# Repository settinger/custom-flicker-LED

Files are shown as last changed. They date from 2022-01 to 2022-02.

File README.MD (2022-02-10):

# A different interpretation of "programmable LED"

TL;DR I'm investigating if I can attach a very very small circuit to a through-hole LED to run a custom programmed pattern, similar to a candle-flicker LED.

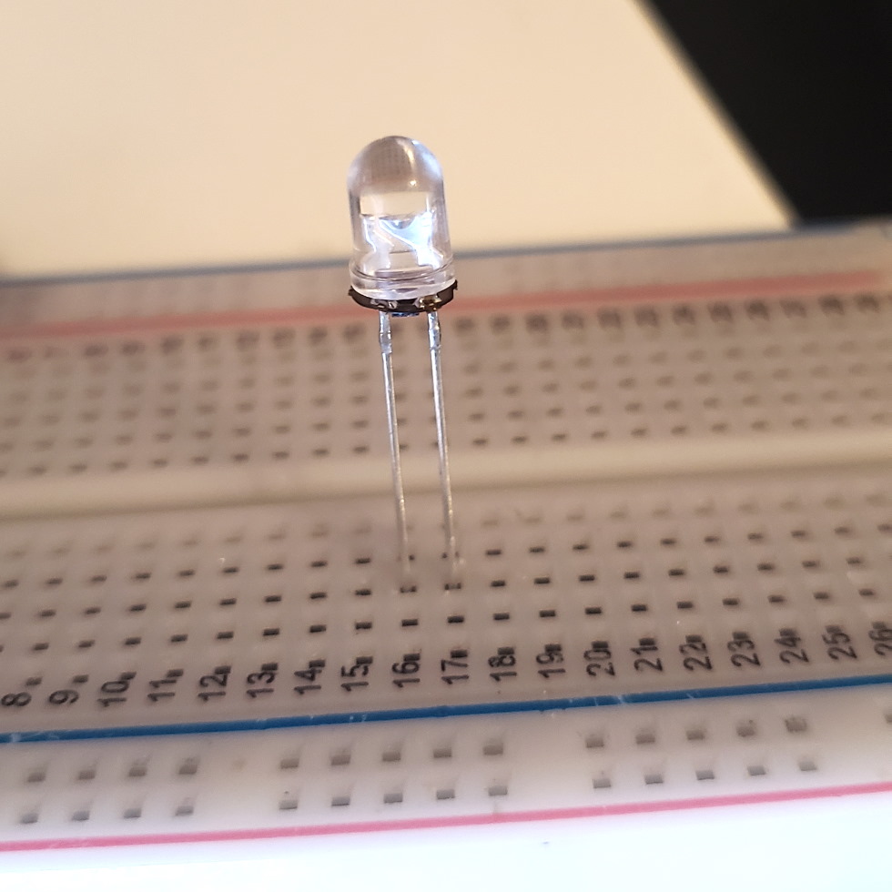
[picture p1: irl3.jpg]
A photograph of a 5mm through-hole LED with a small PCB just barely visible on the underside of the lens


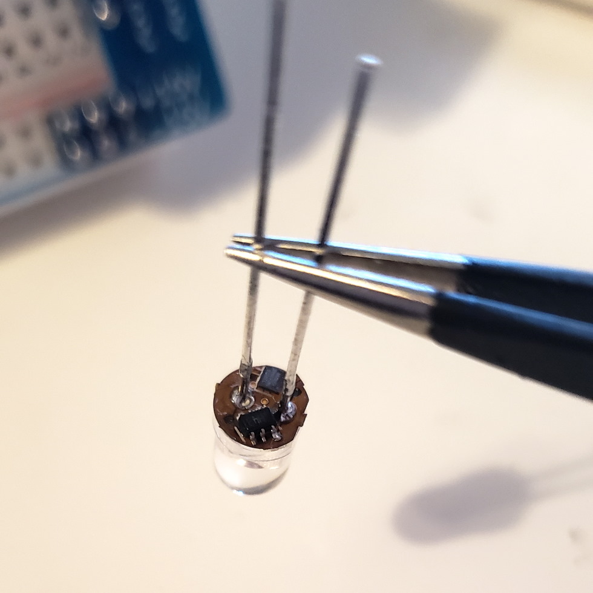
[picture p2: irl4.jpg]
A photograph of a 5mm through-hole LED held in tweezers to expose the small PCB on the underside of the lens


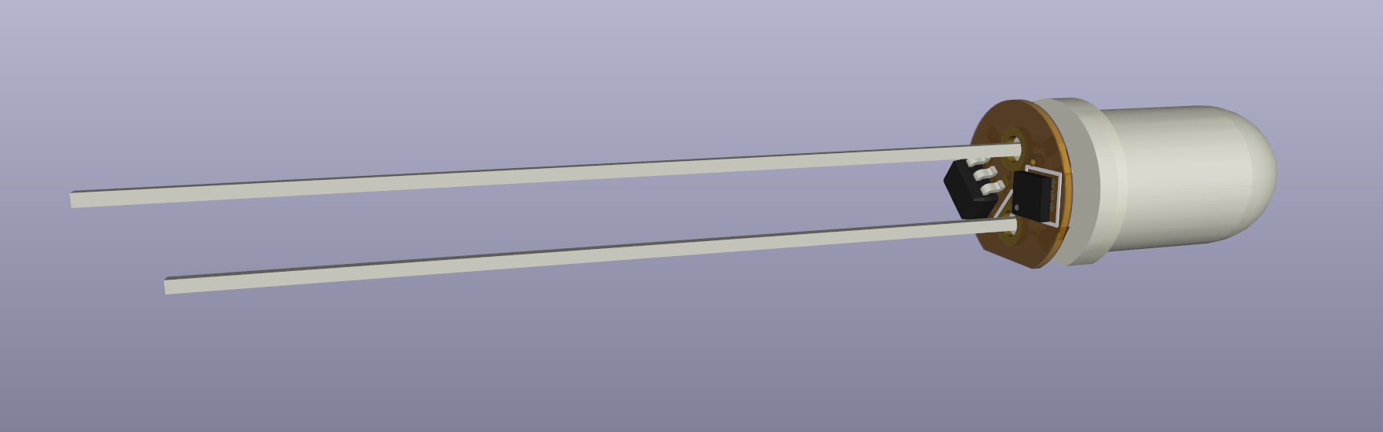
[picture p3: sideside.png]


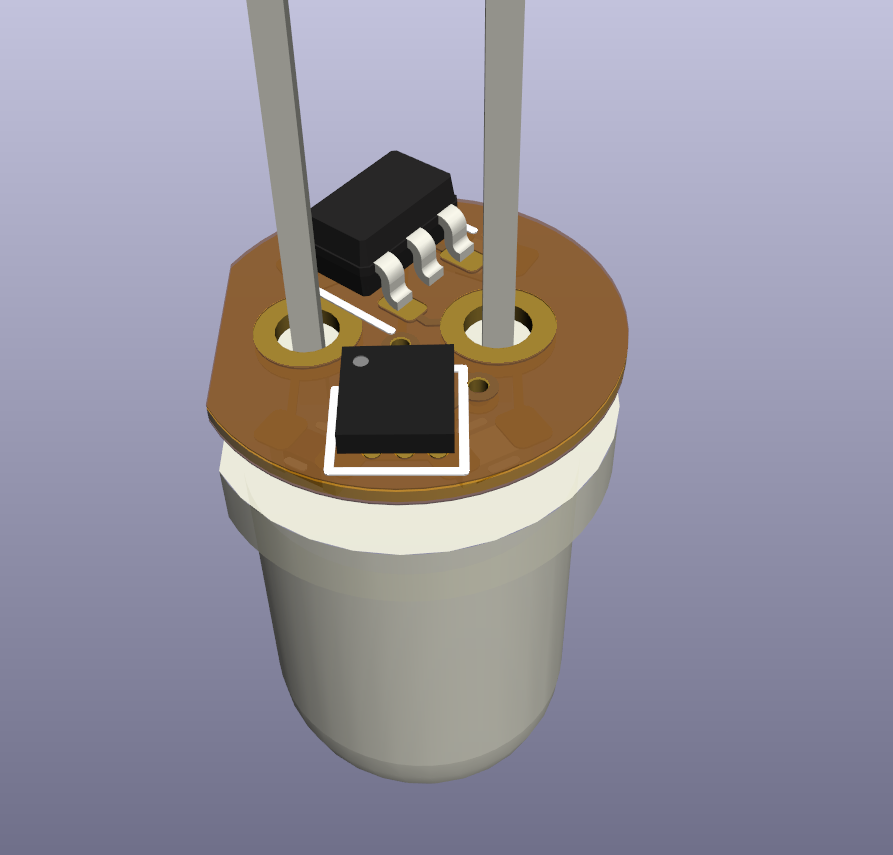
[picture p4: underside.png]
A 3d render of a 5mm through-hole LED with a small PCB on the underside of the lens


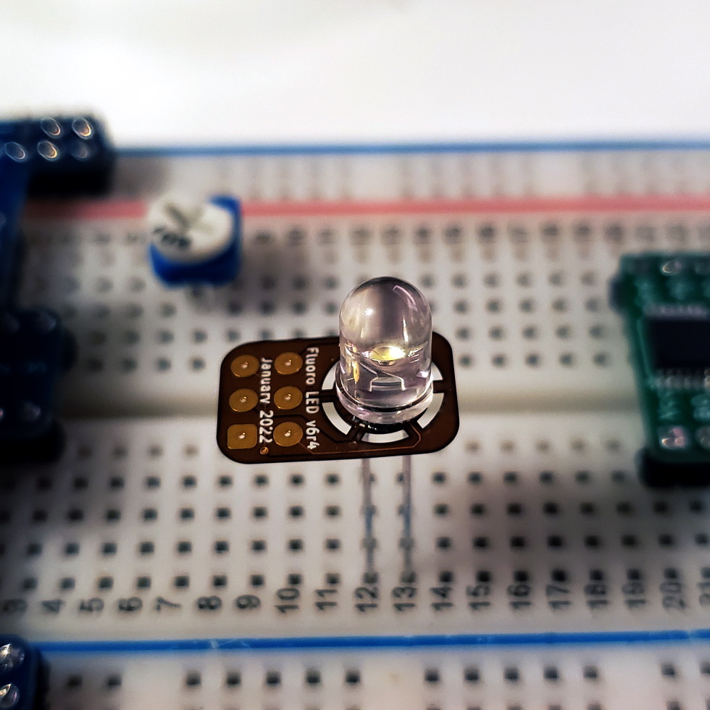
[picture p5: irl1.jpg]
A photograph of a 5mm through-hole LED with a small PCB on the underside of the lens and programming pads sticking out


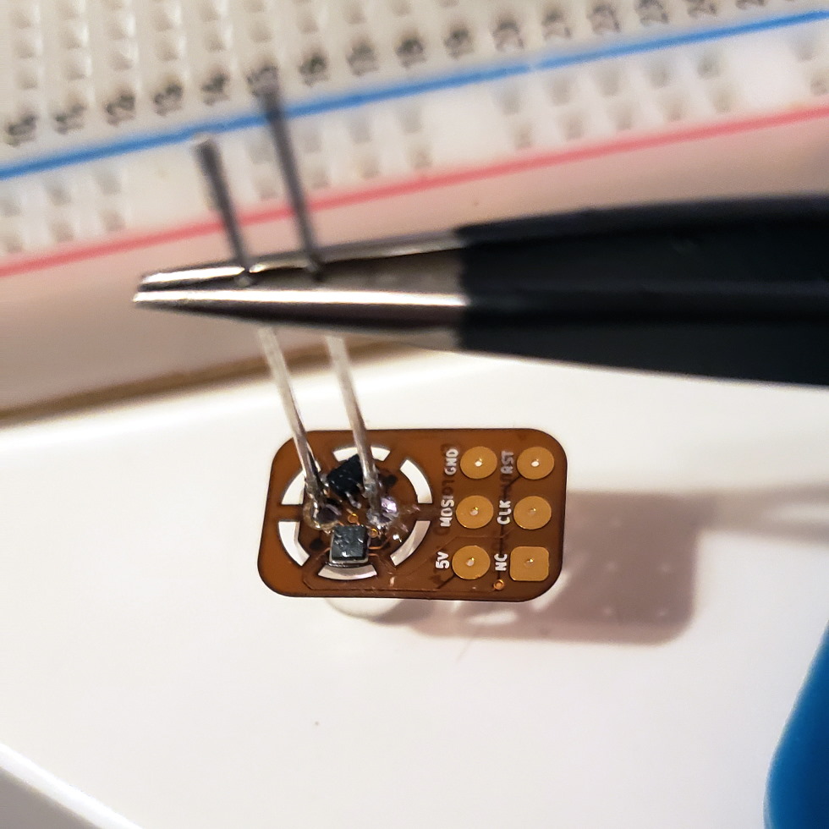
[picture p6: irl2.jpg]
A photograph of a 5mm through-hole LED held in tweezers to expose the small PCB on the underside of the lens, programming pins sticking out


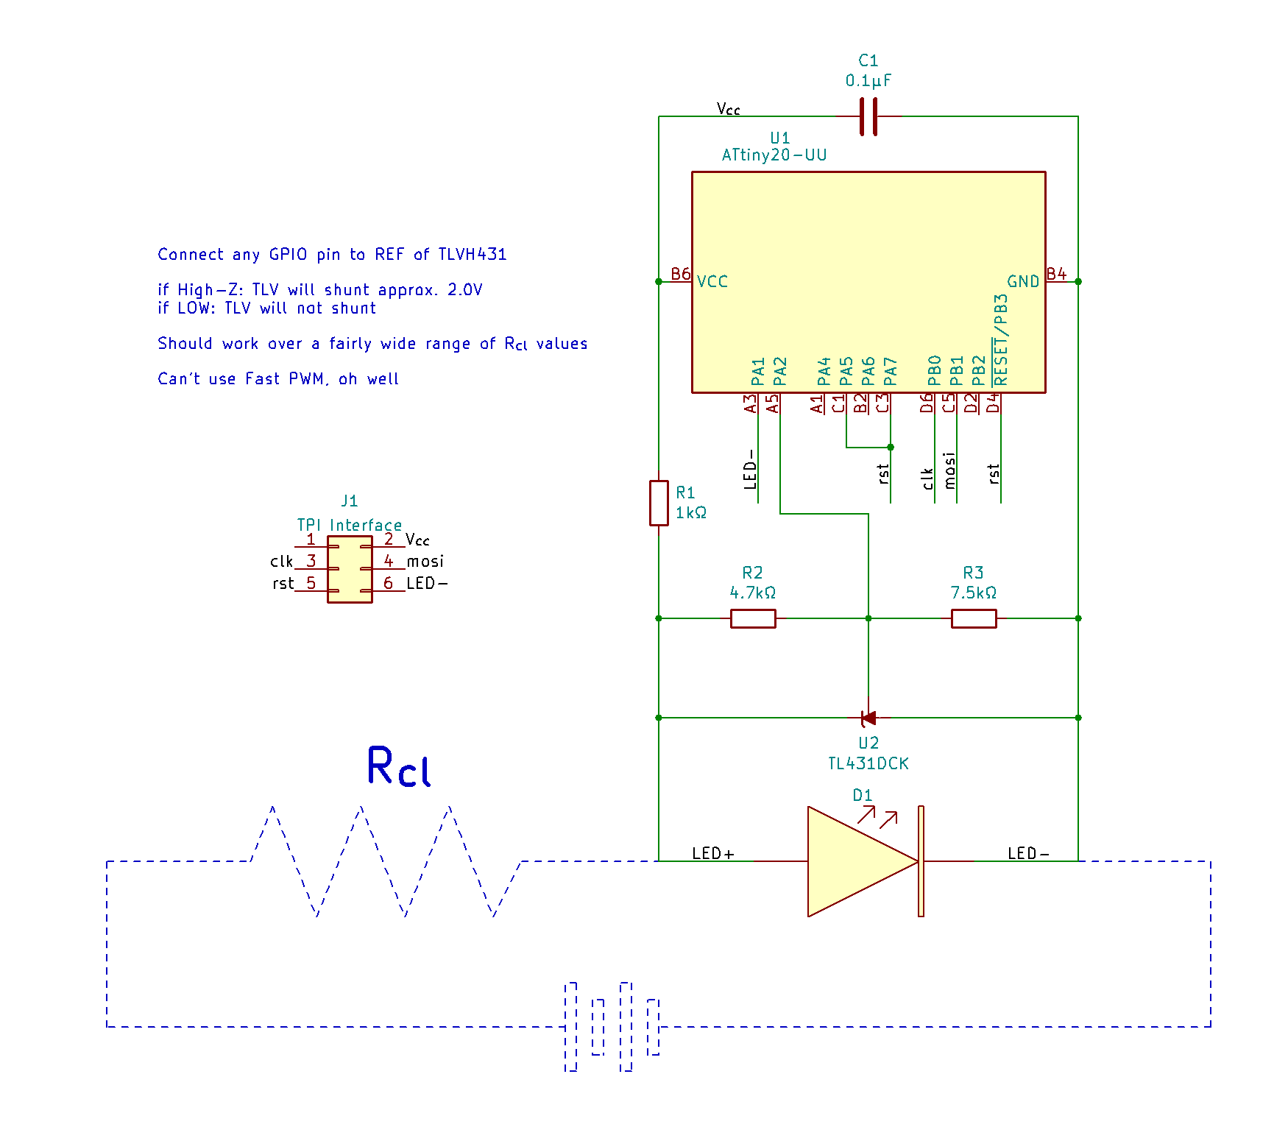
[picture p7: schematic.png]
The schematic of the aforementioned small PCB


## The Concept

A flicker LED is an LED that flickers. More specifically, it is a _drop-in replacement_ for a conventional LED—no need to change the current-limiting resistor, no new calculations for forward voltages, it works just the same as a conventional LED. And they're cheap, too! If you want an LED that flickers like a candle (or one that blinks at a set frequency and duty cycle) you are set for life.

But what if you want a different LED light pattern? In my specific case, I want an LED that turns on like a struggling fluorescent bulb. Or one that stays off most of the time, then suddenly lights up the room like lightning. Or a pseudo-status LED that blinks at random frequencies to trick the viewer into thinking some complex process is running. Or...anything, really. A programmable LED!

Do programmable LEDs like this exist? Obviously the WS2812b and similar LEDs exist, and those are frequently called "programmable LEDs". But those are pretty different than, say, a flicker LED. You still need a controller of some variety to tell the WS2812b what pattern to perform, which is not the case for a flicker LED, and not the case for the LEDs I'm envisioning.

## The Circuit

So can it be done? Without designing a custom IC and embedding it in a custom LED casing? I need a solution compatible with a stock LED. And that means the solution needs to exist _in parallel with the LED_. I'm envisioning a small PCB nestled underneath a 5mm through-hole LED. Soldered in place between the existing legs, no cuts or modifications to the LED itself.

What microcontroller is small enough to fit under a 5mm through-hole LED? I know of two: the WLCSP-12 ATtiny20 (1.55×1.43 mm) and the WLP-16 MAX32660 (1.55×1.57 mm). It's true that I've been meaning to get better with ARM systems, but for now I'll stick with the more familiar AVR-based ATtiny20.

Both those microcontrollers require at least 1.8V to operate. A white LED drawing between 1 and 20 mA will have a forward voltage in roughly the 2.4 - 3.1 V range. That means a microcontroller in parallel can be powered while the LED is on! However, if the LED shuts off, the voltage across it drops to 0V and the microcontroller will shut off as well. To get around this, we can make the LED super dim instead of completely turned off. If we use a shunt to get the LED forward voltage into the 1.8 - 2.0 V range, the microcontroller can stay on while the LED light output is undetectable. A TLVH431 adjustable shunt lets us keep the same forward voltage, regardless of if the shunt is carrying 1 mA or 20 mA, which makes things more consistent than a Zener diode can do.

My original plan was to shunt current around the LED using a BJT driven by an I/O pin on the microcontroller. This would be paired with a Zener diode to keep the LED voltage at at least 1.8V, to ensure the microcontroller has enough power. There were some issues with this approach! For one thing, I learned that low-value Zeners have much more variation in their breakdown voltages. A diode sold as a 1.8V Zener might, at a current of 10 mA, have a breakdown voltage closer to 2.6V; this wouldn't dim the LED at all!

Another issue was the transistor. I didn't realize that I could sink ~20 mA directly into these microcontrollers' GPIO pins! In fact, the ATtiny20 GPIO can source/sink 40 mA, and the MAX32660 can do 25. This means the current being diverted around the LED can go through the microcontroller, instead of an external transistor. Thank you to [cpldcpu](https://cpldcpu.wordpress.com) for pointing this out to me! I don't know what led me to think that a BGA ATtiny could handle less current than SOIC or DIP equivalents. That set off a cascade of design adjustments that led to the current very-low-component-count design.

## Putting it together

A photograph of a 5mm through-hole LED with a small PCB on the underside of the lens and programming pads sticking out

It's working! [Here is a video of the flicker in action](https://twitter.com/DHammarskjold/status/1491195660074627072). The flicker animation is a port of one kindly provided by [Emily Velasco](https://twitter.com/MLE_Online), which you can obtain in the `code/` folder.

[As you can see here](https://twitter.com/DHammarskjold/status/1490858013917208579), there was a (relatively) large PCB still attached to the LED. Those are the programming pads, so I can tweak the program on the ATtiny20 until I decide to trim off the excess parts.

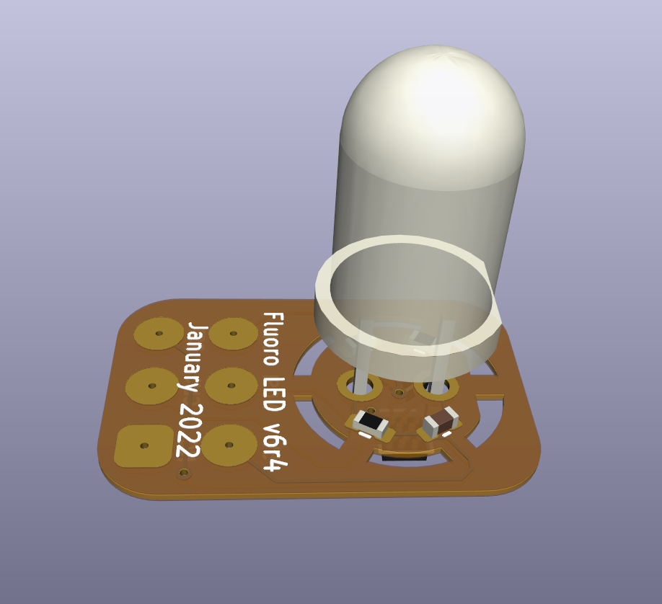
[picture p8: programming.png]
A 3d render of the small PCB inside a larger PCB with pads for connecting a programmer


There are components on both sides of the PCB. I put the ATtiny20 and TLVH431 on first, using a hot plate. Then I programmed the tiny20, and finally I hand-soldered the 0402 passives. I used a 47kΩ and a 68kΩ resistor instead of the desired 4.7kΩ and 7.5kΩ ones because that's what I had on hand.

[Here is a tweet showing my protoboard circuit](https://twitter.com/DHammarskjold/status/1483334537580998658), working as expected with larger versions of each part. This helped me dial in the right resistor values and measure the range of current that kept the board functioning. According to my cheap ammeter, the microcontroller functions properly on a supply as low as 0.5 mA and as high as 20 mA, which I'm thrilled to see.

Please let me know if you have some suggestions for improvements to the fluorescent-flicker animation, or if there are other programmable LED animations you'd like to see! I have a few ideas for a 5mm RGB LED, but that's a project for another time....

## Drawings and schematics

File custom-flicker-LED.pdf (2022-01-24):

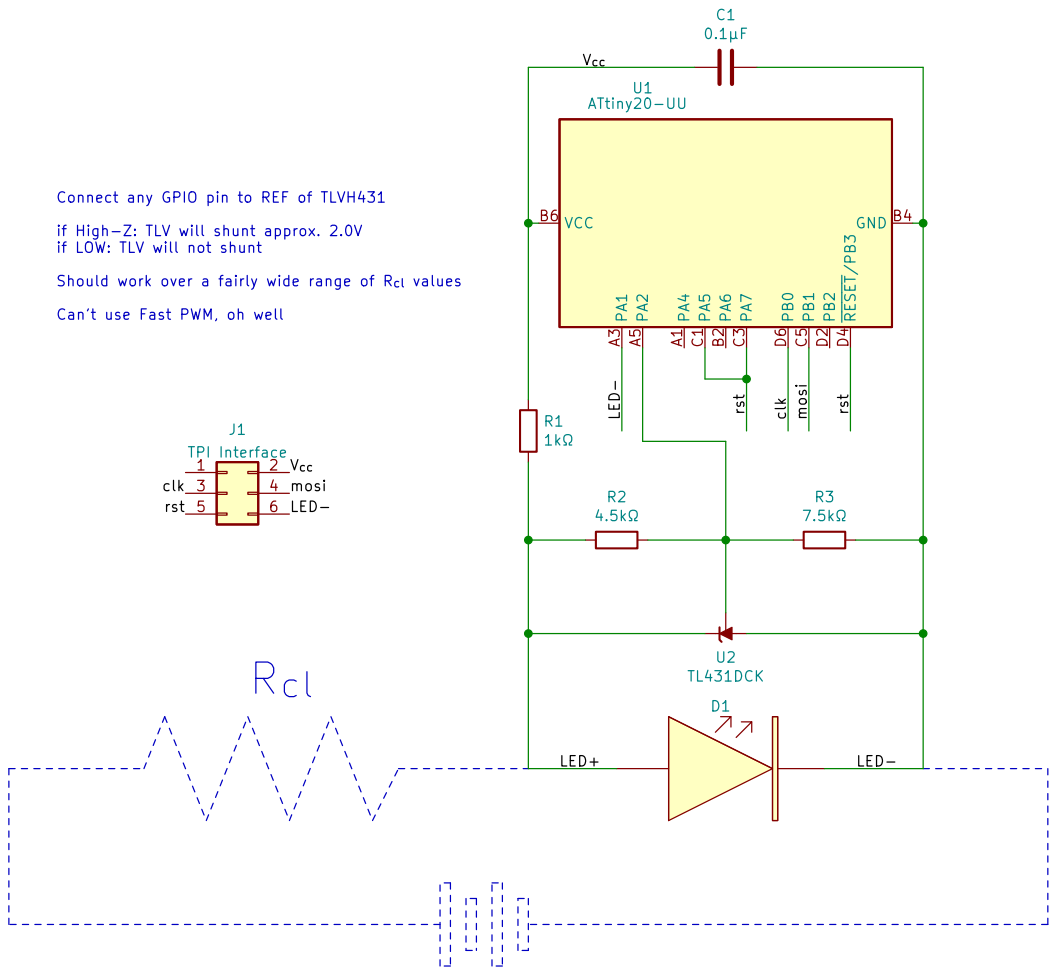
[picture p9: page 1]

Connect any GPIO pin to REF of TLVH431

if High-Z: TLV will shunt approx. 2.0V
if LOW: TLV will not shunt Should work over a fairly wide range of R_{cl} values Can't use Fast PWM, oh well

File: custom-flicker-LED.kicad_sch Sheet: /
Id: 1/1 Title:

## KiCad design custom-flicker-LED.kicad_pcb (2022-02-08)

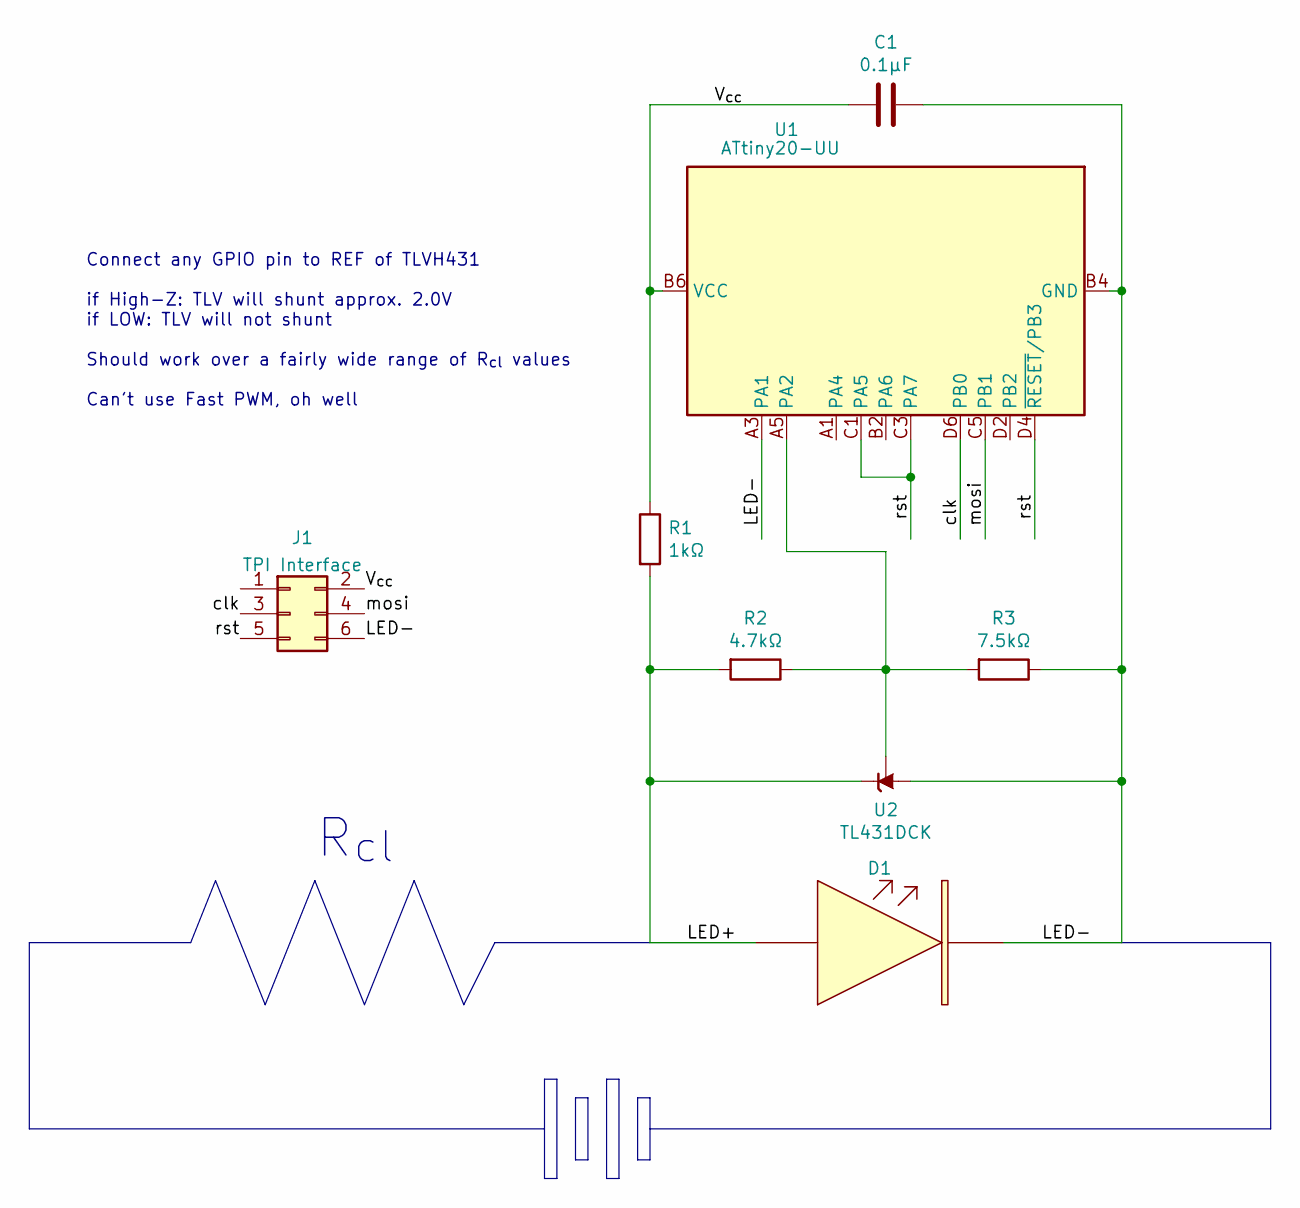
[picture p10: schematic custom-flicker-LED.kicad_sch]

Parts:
C1: 0.1μF; C_0402_1005Metric
D1: LED_big; LED_D5.0mm_Clear
J1: TPI Interface; PinHeader_2x03_P2.54mm_Vertical
R1: 1kΩ; R_0402_1005Metric
R2: 4.7kΩ; R_0402_1005Metric
R3: 7.5kΩ; R_0402_1005Metric
U1: ATtiny20-UU; WLCSP-12_1.403x1.555mm_P0.4mm_Stagger
U2: TL431DCK; SOT-363_SC-70-6

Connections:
/LED+: D1.2 (A), R1.2, R2.2, U2.1 (K)
/LED-: C1.1, D1.1 (K), J1.6, R3.1, U1.A3 (PA1), U1.B4 (GND), U2.6 (A)
/V_{cc}: C1.2, J1.2, R1.1, U1.B6 (VCC)
/clk: J1.3, U1.D6 (PB0)
/mosi: J1.4, U1.C5 (PB1)
/rst: J1.5, U1.C1 (PA5), U1.C3 (PA7), U1.D4 (~RESET/PB3)
unnamed: R2.1, R3.2, U1.A5 (PA2), U2.3 (REF)

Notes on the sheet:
R_{cl}
Connect any GPIO pin to REF of TLVH431 if High-Z: TLV will shunt approx. 2.0V if LOW: TLV will not shunt Should work over a fairly wide range of R_{cl} values Can't use Fast PWM, oh well

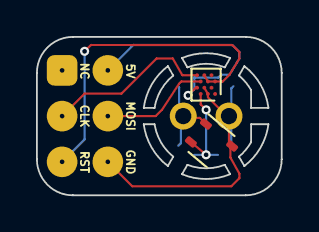
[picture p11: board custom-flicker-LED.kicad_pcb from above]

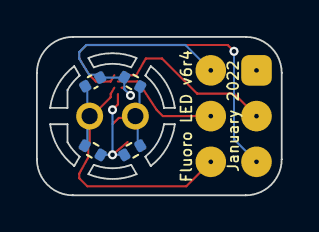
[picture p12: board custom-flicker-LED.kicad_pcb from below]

Board: 2 copper layers, 13.6 x 8.8 mm, 8 parts (5 on the bottom side), 7 nets.

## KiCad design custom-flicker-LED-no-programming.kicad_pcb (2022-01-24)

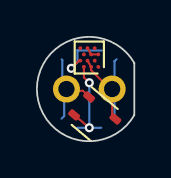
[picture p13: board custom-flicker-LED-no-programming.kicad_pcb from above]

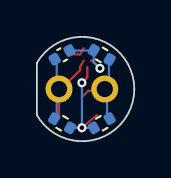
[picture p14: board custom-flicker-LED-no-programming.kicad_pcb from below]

Board: 2 copper layers, 5.4 x 5.8 mm, 7 parts (5 on the bottom side), 5 nets.

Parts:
C1: 0.1μF; C_0402_1005Metric
D1: LED_big; LED_D5.0mm_Clear
R1: 1kΩ; R_0402_1005Metric
R2: 4.5kΩ; R_0402_1005Metric
R3: 7.5kΩ; R_0402_1005Metric
U1: ATtiny20-UU; WLCSP-12_1.403x1.555mm_P0.4mm_Stagger
U2: TL431DCK; SOT-363_SC-70-6

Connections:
/LED+: D1.2 (A), R1.2, R2.2, U2.1 (K)
/LED-: C1.1, D1.1 (K), R3.1, U1.A3 (PA1), U1.B4 (GND), U2.6 (A)
/V_{cc}: C1.2, R1.1, U1.B6 (VCC)
/rst: U1.C1 (PA5), U1.C3 (PA7), U1.D4 (~RESET/PB3)
unnamed: R2.1, R3.2, U1.A5 (PA2), U2.3 (REF)

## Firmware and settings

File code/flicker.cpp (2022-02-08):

/*
 * flicker_t20.cpp
 * A port of this algorithm: https://github.com/emilyvelasco/flickery_light/blob/main/flickery_light_w_warmup.ino
 * Important datasheet: http://ww1.microchip.com/downloads/en/DeviceDoc/atmel-8235-8-bit-avr-microcontroller-attiny20_datasheet.pdf
 *
 * When PA2 is High-Z, current is shunted through TLVH431
 * and LED anode is driven to approximately 2V.
 *
 * When PA2 is LOW, TLV431 is driven as high as possible
 * and current flows through the LED as normal.
 *
 * When PA2 is HIGH, the LED anode is driven to 1.24V
 * which will cause the system to reset. Not advised.
 *
 * Created: 1/16/2022 3:35:08 PM
 * Author : Sam Ettinger <ettingersam@gmail.com> https://github.com/settinger/custom-flicker-LED
 */
#define F_CPU 4000000UL
#include <avr/io.h>
#include <avr/interrupt.h>

// Declare constants and variables
#define INTERRUPT_DELAY 100U                            // Number of processor cycles in the smallest binary code modulation frame
#define NUM_FRAMES 6                                    // Number of binary code modulation frames per period
#define UPDATE_DELAY 20                                 // Number of periods to elapse before re-calculating the LED brightness
volatile unsigned int interruptDelay = INTERRUPT_DELAY; // How many cycles long is the current frame; loops between 100, 200, 400, 800, 1600, 3200
volatile int frame = 0;                                 // Which binary-code-modulation frame we are currently on; loops between 0, 1, 2, 3, 4, 5
volatile unsigned int brightness = 0;                   // A value between 0 and 63 determining the duty cycle of the LED (0: off, 63: fully on)
volatile unsigned char updateDelay = 0;                 // How many periods of binary code modulation have elapsed since LED brightness was last calculated

volatile unsigned int randomLevel;                      // A random number to determine if LED is on or not
volatile unsigned int lightLevel;                       // A random number that is the LED brightness
volatile unsigned int cutoffValue = 127;                // By comparing this to a random 7-bit number we determine how likely the LED is to be on or off at a given moment.
volatile unsigned int bottomRandom = 2;                 // The lowest acceptable brightness for the LED at this current moment
volatile bool slowdown = false;                              // Slows down the speed at which bottomRandom increases

// Write to the 16-bit register pair OCR1A
void setTimer1(unsigned int i) {
	unsigned char sreg;
	sreg = SREG; // Save global interrupt flag
	cli(); // Disable interrupts
	OCR1A = i; // Write value to register pair
	TCNT1 = 0; // Reset counter
	SREG = sreg; // Restore global interrupt flag
}

// Set the LED to one of 64 brightness levels
void setBrightness (unsigned int i) {
	brightness = i & 0x3F;
}

// Gather entropy from ADC
int getEntropy(int bits) {
	int entropy = 0;
	for (int bit = 0u; bit < bits; bit++) {
		// Start ADC collection
		ADCSRA |= 1 << ADSC;
		// Wait for ADC conversion to finish (25 clock cycles the first time, 13 cycles afterward)
		while (ADCSRA & 1 << ADSC) {
			;
		}
		// Fetch LSB of ADC result and put it in the entropy variable
		entropy |= (ADC & 1) << bit;
		
		// Delay a little bit before taking next measurement
		if (bit < (bits - 1)) {
			int n = 0;
			while (n < 30) {
				n++;
			}
		}
	}
	return entropy;
}

// Calculate the new brightness
void flicker() {
	// Pick random number to determine if light is on or off
	randomLevel = getEntropy(7);
	
	// Lower cutoff level over time to reduce flicker gradually
	if (cutoffValue > 0) {
		cutoffValue--;
	}
	
	// If LED should be on, set it to the calculated brightness
	if (randomLevel >= cutoffValue) {
		lightLevel = getEntropy(5);
		lightLevel = bottomRandom + (lightLevel % (63 - bottomRandom));
		setBrightness(lightLevel);
	} else {
		setBrightness(0);
	}
	
	// Increase minimum brightness value until full brightness is achieved, but maintain some flicker
	slowdown = !slowdown;
	if (slowdown) {
		bottomRandom++;
		if (bottomRandom > 50) {
			bottomRandom = 50;
		}
	}
}

int main(void) {
	// Set clock prescaler to 4 (i.e. 2 MHz system clock) (Datasheet p.21)
	CCP = 0xD8;
	CLKPSR = 0b0001;
	
	// Set PA2 to high-Z condition initially (Datasheet p.44)
//	PORTCR = 1 << BBMA; // Break-before-make enabled; I don't know if this helps at all
	DDRA = 0;           // All Port A pins configured as inputs
	PORTA = 0;          // All Port A pins driven low; probably not necessary
	PUEA = 0;	        // All Port A pullup resistors disconnected; putting all Port A pins into High-Z mode
	
	// Configure Timer1 to CTC Mode (datasheet p.96)
	TCCR1A = 0b00 << WGM10;
	TCCR1B = 0b01 << WGM12 | 0b001 << CS10; // no prescaler
	TIMSK = 1 << OCIE1A; // Enable Timer1 Output Compare A Match Interrupt
	
	// Enable ADC for gathering entropy -- PA4 and PA6 are not connected to anything, so probably good choices (datasheet p.121)
	ADCSRA = 1 << ADEN | 0b011 << ADPS0; // Enable ADC, set to 500kHz
	//ADCSRB = 1 << ADLAR; // Left-adjust ADC for faster, less accurate readings
	ADMUX = 0b0110 << MUX0; // Connect ADC to PA6
	
	// Write to the 16-bit OCR1A register pair to set number of cycles before first overflow interrupt occurs (datasheet p.96)
	setTimer1(interruptDelay);
	
	// Set initial brightness
	setBrightness(0);
	
	// Enable interrupts
	sei();
	
	while (1) {
	}
}

/* Timer1 Overflow Interrupt:
 * Interrupt is triggered after n system clock cycles,
 * where n loops between [100, 200, 400, 800, 1600, 3200].
 * If LED is supposed to be ON, write 1<<DDA2 to DDRA register.
 * If LED is supposed to be OFF, write 0<<DDA2 to DDRA register.
 * Every few 3200-cycle interrupts, update brightness
 */

ISR(TIM1_COMPA_vect) {
	// Disable interrupts during this!
	unsigned char sreg;
	sreg = SREG; // Register of global interrupt flags
	cli();       // Disable interrupts
	
	// Advance to next frame
	// If the coming frame will be the last frame of a BCM period,
	// then check if it's time to update the LED brightness.
	// If the coming frame is the first frame of a BCM period, 
	// set the interrupt delay back to its original (low) value.
	// These could be combined into one if statement, I'm sure.

	frame = (frame+1) % NUM_FRAMES;
	
	if (frame == NUM_FRAMES-1) {
		updateDelay++;
		if (updateDelay == UPDATE_DELAY) {
			updateDelay = 0;
			
			// brightness change here
			flicker();
		}
	}
	
	if (frame == 0) {
		interruptDelay = INTERRUPT_DELAY;
	} else {
		interruptDelay = interruptDelay << 1;
	}

	// Turn LED on or off for this frame of binary code modulation
	if (brightness & 1<<frame) {
		DDRA |= 1 << DDA2;
	} else {
		DDRA &= ~(1 << DDA2);
	}
	
	setTimer1(interruptDelay);
	
	SREG = sreg; // Restore interrupts
}

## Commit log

2021-12-20 First public commit
    [custom-flicker-LED.kicad_pcb, custom-flicker-LED.sch]
2022-01-24 Migrated to KiCad 6 and a much better circuit
    [custom-flicker-LED-no-programming.kicad_pcb, custom-flicker-LED.kicad_pcb, custom-flicker-LED.kicad_sch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]
2022-02-08 Update to show it working IRL, wooooo
    [custom-flicker-LED.kicad_pcb, custom-flicker-LED.kicad_sch]
